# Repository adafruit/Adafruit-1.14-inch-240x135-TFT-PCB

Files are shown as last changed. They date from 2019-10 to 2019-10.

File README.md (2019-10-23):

## Adafruit 1.14" 240x135 Color TFT Display + MicroSD Card Breakout - ST7789 PCB

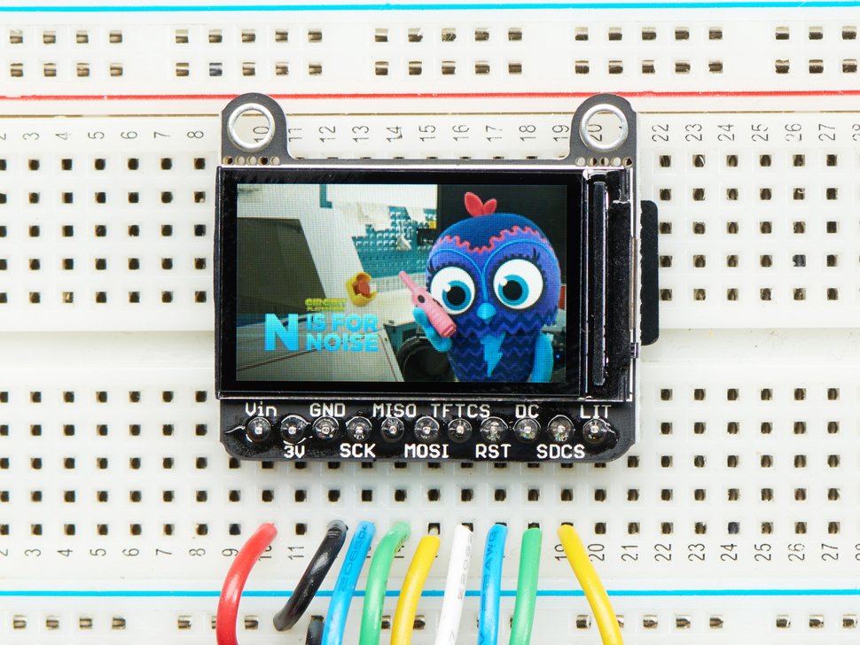
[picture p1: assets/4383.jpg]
<a href="http://www.adafruit.com/products/4383"><br/>
Click here to purchase one from the Adafruit shop</a>

PCB files for the Adafruit 1.14" 240x135 Color TFT Display + MicroSD Card Breakout - ST7789. 

Format is EagleCAD schematic and board layout
* https://www.adafruit.com/product/4383

### Description

Say hello to our 1.14" 240x135 Color TFT Display w/ MicroSD Card Breakout – we think it's T-F-Terrific! It's the size of your thumbnail, with glorious 240x135 high res pixel color. This very very small display is only 1.14" diagonal, packed with RGB pixels, for making very small high-density displays.

We've been looking for a display like this for a long time - it's so small only 1.14" diagonal but has a high density 260 ppi, 240x135 pixel display with full-angle viewing. It looks a lot like our 0.96" 160x80 display, but has 2.5x as many pixels. We've seen displays of this caliber used in smartwatches and small electronic devices but they've always been MIPI interface. Finally, we found one that is SPI and has a friendly display driver, so it works with any and all microcontrollers or microcomputers!

This lovely little display breakout is the best way to add a small, colorful and very bright display to any project. Since the display uses 4-wire SPI to communicate and has its own pixel-addressable frame buffer, it can be used with every kind of microcontroller. Even a very small one with low memory and few pins available! The 1.14" display has 240x135 16-bit full color pixels and is an IPS display, so the color looks great up to 80 degrees off axis in any direction. The TFT driver (ST7789) is very similar to the popular ST7735, and our Arduino library supports it well.

Our breakout has the TFT display soldered on (it uses a delicate flex-circuit connector) as well as a ultra-low-dropout 3.3V regulator and a 3/5V level shifter so you can use it with 3.3V or 5V power and logic. We also had a little space so we placed a microSD card holder so you can easily load full color bitmaps from a FAT16/FAT32 formatted microSD card. The microSD card is not included, [but you can pick one up here](http://www.adafruit.com/products/102).

Of course, we wouldn't just leave you with a datasheet and a "good luck!" - [we've written a full open source graphics library that can draw pixels, lines, rectangles, circles, text and bitmaps as well as example code and a wiring tutorial](https://learn.adafruit.com/adafruit-1-3-and-1-54-240-x-240-wide-angle-tft-lcd-displays/circuitpython-displayio-quickstart). The code is written for Arduino IDE but can be easily ported to your favorite microcontroller!

### License

Adafruit invests time and resources providing this open source design, please support Adafruit and open-source hardware by purchasing products from [Adafruit](https://www.adafruit.com)!

Designed by Limor Fried/Ladyada for Adafruit Industries.

Creative Commons Attribution/Share-Alike, all text above must be included in any redistribution. 
See license.txt for additional details.

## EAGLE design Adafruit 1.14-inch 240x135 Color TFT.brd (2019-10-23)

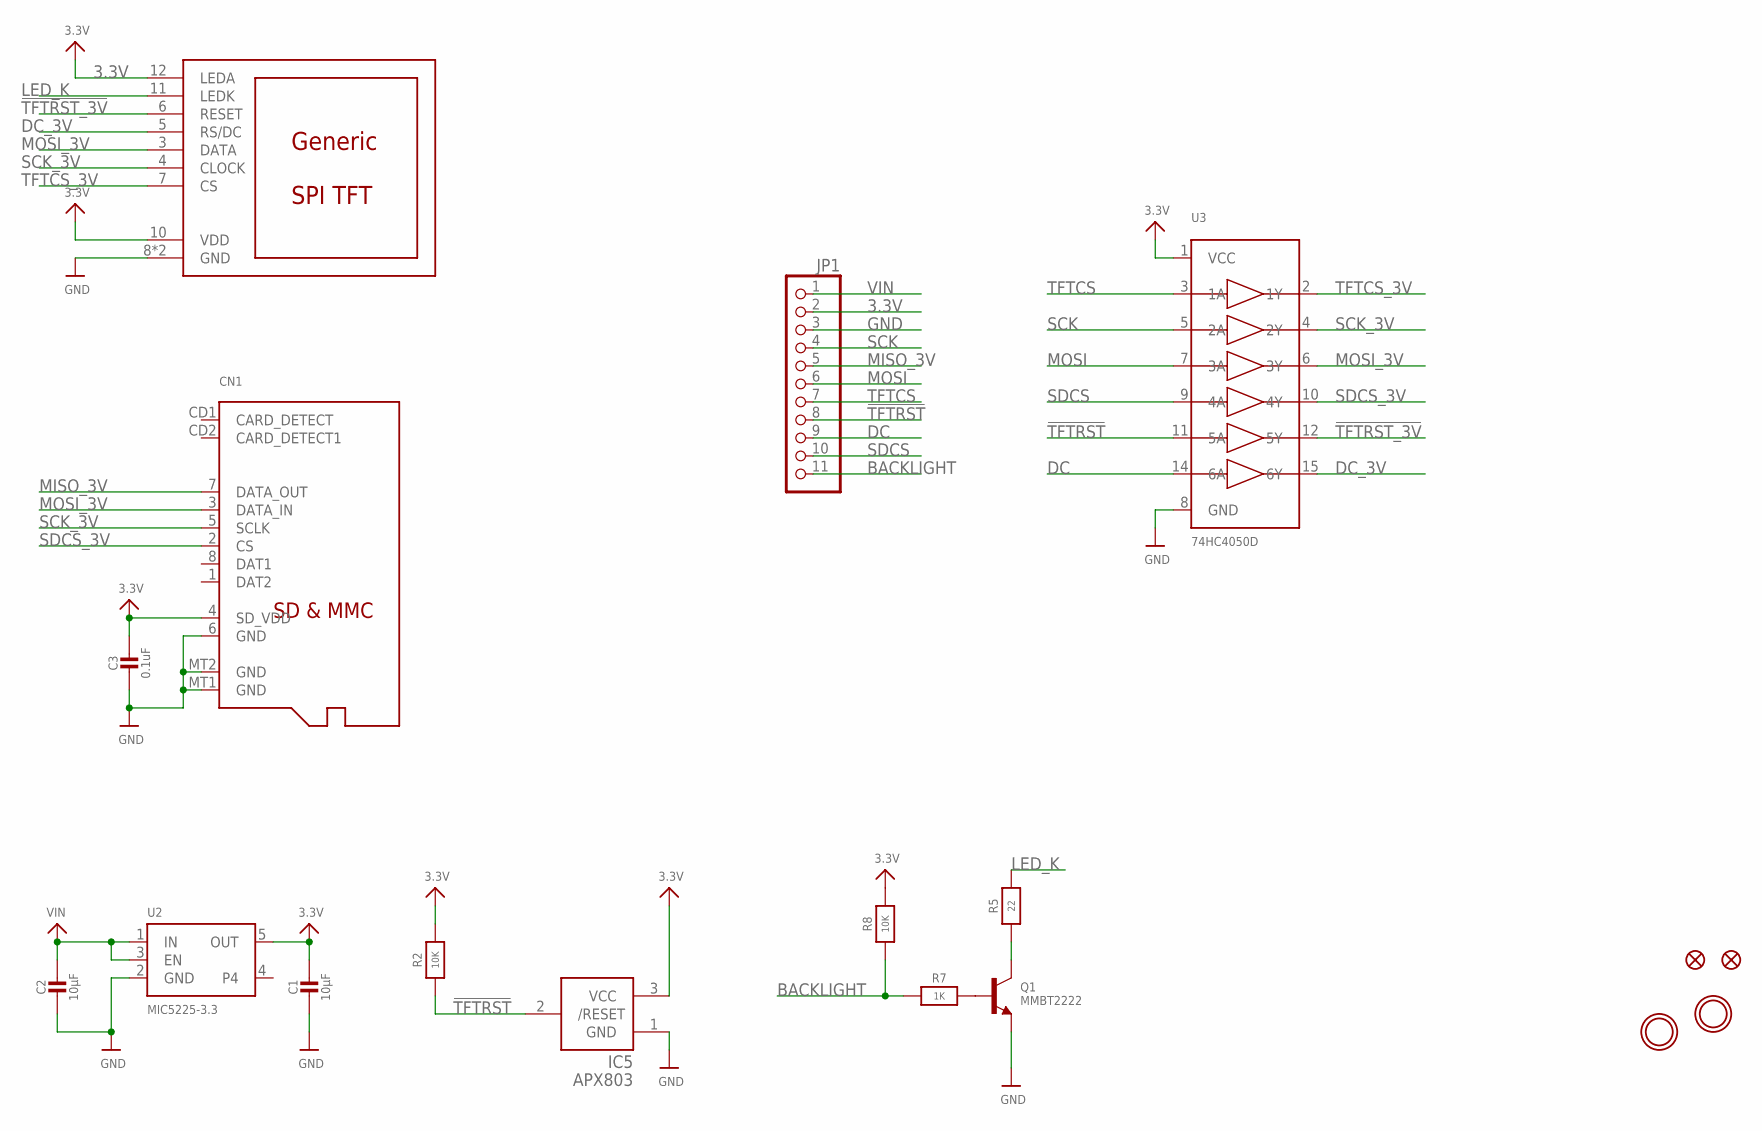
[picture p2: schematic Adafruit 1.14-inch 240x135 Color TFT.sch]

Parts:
C1, C2: 10µF; 0805-NO
C3: 0.1uF; 0805-NO
CN1: MICROSD
DISP1: DISP_LCD_GENERIC_SPI_1.14IN_240X135_WRAPUNDER; TFT_1.14IN_240X135_WRAPUNDER
FID1, FID2: FIDUCIAL_1MM
IC5: APX803; SOT23
JP1: HEADER-1X11; 1X11_ROUND
Q1: MMBT2222; SOT23-WIDE
R2, R8: 10K; 0603-NO
R5: 22; 0603-NO
R7: 1K; 0603-NO
U2: MIC5225-3.3; SOT23-5
U3: 74HC4050D; SOIC16
U$9, U$10: MOUNTINGHOLE2.5; MOUNTINGHOLE_2.5_PLATED

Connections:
3.3V: C1.1, C3.1, CN1.4 (SD_VDD), DISP1.10 (VDD), DISP1.12 (LEDA), IC5.3 (VCC), JP1.2, R2.2, R8.2, U2.5 (OUT), U3.1 (VCC)
!TFTRST: IC5.2 (/RESET), JP1.8, R2.1, U3.11 (5A)
!TFTRST_3V: DISP1.6 (RESET), U3.12 (5Y)
BACKLIGHT: JP1.11, R7.1, R8.1
DC: JP1.9, U3.14 (6A)
DC_3V: DISP1.5 (RS/DC), U3.15 (6Y)
GND: C1.2, C2.2, C3.2, CN1.6 (GND), CN1.MT1 (GND), CN1.MT2 (GND), DISP1.8 (GND), DISP1.13 (GND), IC5.1 (GND), JP1.3, Q1.2 (E), U2.2 (GND), U3.8 (GND)
LED_K: DISP1.11 (LEDK), R5.2
MISO_3V: CN1.7 (DATA_OUT), JP1.5
MOSI: JP1.6, U3.7 (3A)
MOSI_3V: CN1.3 (DATA_IN), DISP1.3 (DATA), U3.6 (3Y)
unnamed: Q1.1 (B), R7.2
unnamed: Q1.3 (C), R5.1
SCK: JP1.4, U3.5 (2A)
SCK_3V: CN1.5 (SCLK), DISP1.4 (CLOCK), U3.4 (2Y)
SDCS: JP1.10, U3.9 (4A)
SDCS_3V: CN1.2 (CS), U3.10 (4Y)
TFTCS: JP1.7, U3.3 (1A)
TFTCS_3V: DISP1.7 (CS), U3.2 (1Y)
VIN: C2.1, JP1.1, U2.1 (IN), U2.3 (EN)

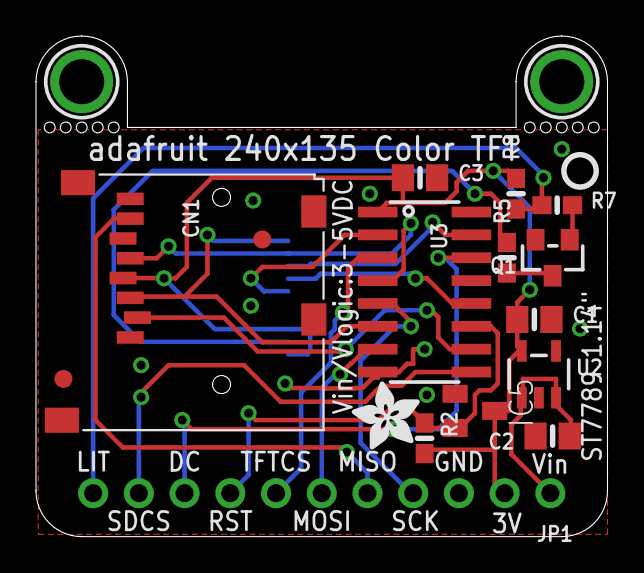
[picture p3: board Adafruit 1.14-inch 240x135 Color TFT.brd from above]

Board: 2 copper layers, 31.8 x 27.8 mm, 20 parts (1 on the bottom side), 20 nets.

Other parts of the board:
U$4: MICROSD; ADAFRUIT_3.5MM
U$6: PCBFEAT-REV-040

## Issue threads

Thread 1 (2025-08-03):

SD Card Initialization Failure on Adafruit ST7789 + SD Combo with RP2040Zero

i8it, 2025-08-03:
I struggled when trying to use the Adafruit ST7789 TFT display with built-in SD card slot on RP2040-based boards like the RP2040Zero or Raspberry Pi Pico. A common and extremely frustrating problem is this:

    The SD card seems to initialize ("SD init OK"), but file reads always fail, or no files are found — even when the card is correctly formatted and wired.

This can happen even after following Adafruit’s official examples.
✅ Root Cause: Improper SPI Bus Startup for Shared Devices

The problem stems from how the SPI bus is shared between the display and the SD card, and how the SD card must be properly "woken up" with dummy clock cycles before initialization.

Although the Adafruit examples assume hardware behaves in an ideal way, the specific timing and startup behavior of some boards (like the RP2040Zero) require a more careful SPI setup to get reliable communication.
🛠️ Solution: Manual SPI1 Setup + Dummy Clock Pulses Before SD.begin()

Here’s what worked:

    Use SPI1, not default SPI, for the display and SD card (Adafruit’s code uses SPI by default, which may conflict with onboard peripherals).

    Manually set SCK, MOSI, and MISO pins before calling .begin().

    Send 74 or more dummy clock cycles with CS low before initializing the SD card. This is part of the SD card spec to ensure it's fully awake.

    Use SdSpiConfig() with SHARED_SPI mode to make it clear that the display and SD card share the same SPI bus.

📌 Notes for displaying a BMP file (code below)

    The BMP must be 24-bit, uncompressed, and in the root directory of the SD card.

    The SD card should be formatted with the official SD Card Formatter tool.

[spi Adafruit.txt](https://github.com/user-attachments/files/21565915/spi.Adafruit.txt)

    Tested working on RP2040Zero with 512MB and 8GB SD cards.
